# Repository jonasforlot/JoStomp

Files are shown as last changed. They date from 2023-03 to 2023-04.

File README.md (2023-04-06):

# JoStomp HX

This project is a mini MIDI controller for HX Stomp. It allows easy access to the 3 snapshots of a preset, while retaining the possibility of remaining in Footswitch mode on the HX. This offers many more possibilities and flexibility than a double TRS footswitch.
This pedal is also configured to scroll through the presets and provides access to a mini RC20 type looper.

It's not my work ! I just followed mattzws' advice on this page (the article is incredibly clear and detailed !) :

https://github.com/mattzzw/midi_muppet_hx_2btn

A big thanks to him !

I just customized this pedal by adding a button, then modified the code to suit my needs ;)

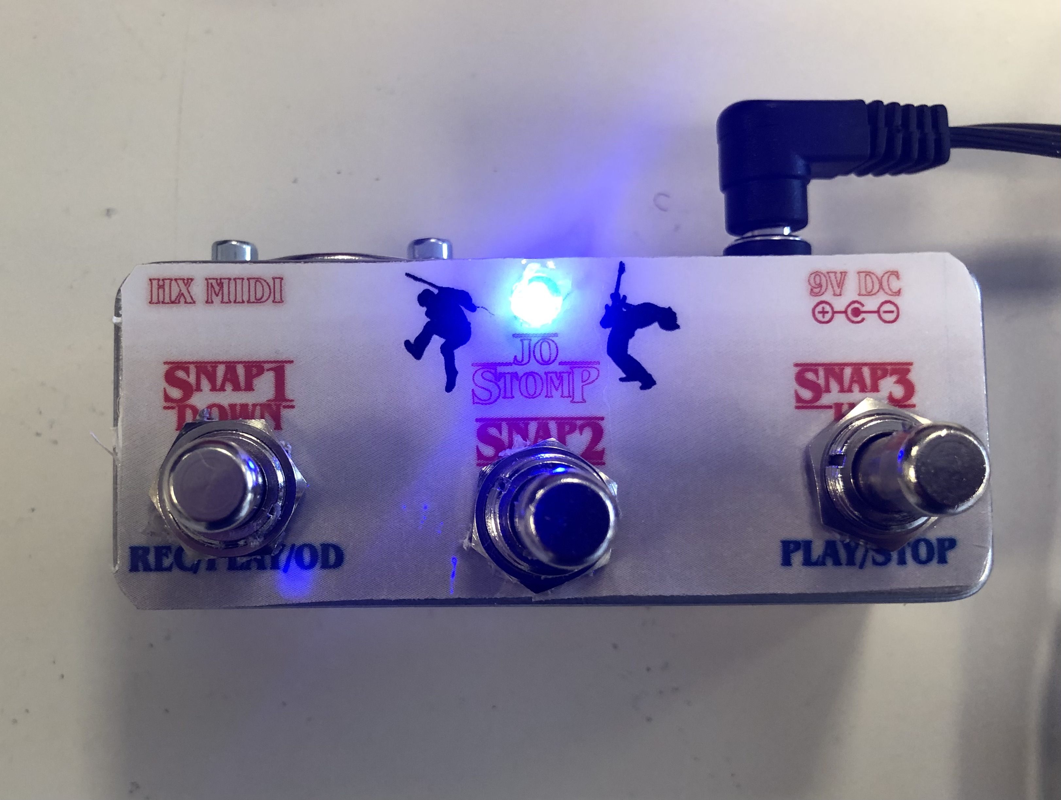
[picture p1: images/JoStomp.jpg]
JoStomp HX


**DEMO VIDEO HERE**
me (https://www.youtube.com/watch?v=dttxhMk9ur8&t=41s)

<a href="https://www.youtube.com/watch?v=dttxhMk9ur8&t=41s" target="_blank">DEMO VIDEO</a>

The JoStomp HX can

- select the three **snapshots**
- **scroll** up/down through **presets** 
- act as a two button **LOOPER** controller
    
    ... and can do more if we want !
    
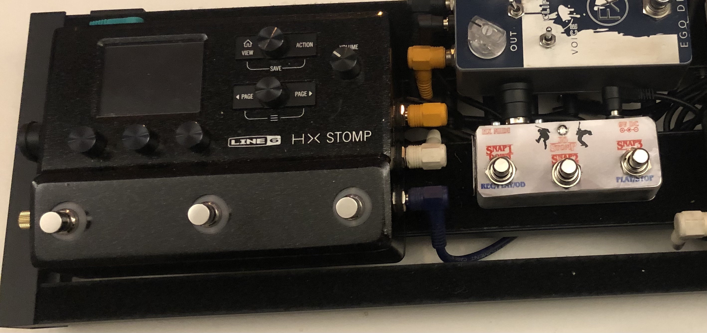
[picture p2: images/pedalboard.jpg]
pedalboard


## JoStomp Modes

| Mode |  LED  |
|---|---|
| Snapshot| **Green** |
| Scroll preset|  **Red** |
| Looper  | **Purple** ----------> **FEATURES** ->  Record : **flash red**  -----  Play : **green**  -----  Overdub : **yellow**|

To select a mode (snapshot or scroll presets), press and hold  button **2**

## Using the Modes:
| Mode |  Actions  |
|---|---|
| SCROLL Mode |  <ul><li>buttons **1/3** : preset down/up</li><li>button **2** **long** : mode SNAPSHOT</li><li>buttons **1+3** **both long**: LOOPER mode</li></ul> | 
| SNAPSHOT Mode | <ul><li>buttons **1/2/3** : select snapshot</li><li> button **2** **long** : mode SCROLL</li><li>buttons **1+3** **both long**: LOOPER mode</li></ul> | 
| LOOPER Mode | <ul><li>button **1** : record/play/overdub</li><li>button **3** : play/stop /undo (**long**)</li><li>button **2** : select mode HX (presets, snapshots, footswitch)</li><li>buttons **1+3** **both long**: mode SNAPSHOT</li><li>button **2** **long** : mode SNAPSHOT</li></ul> | 

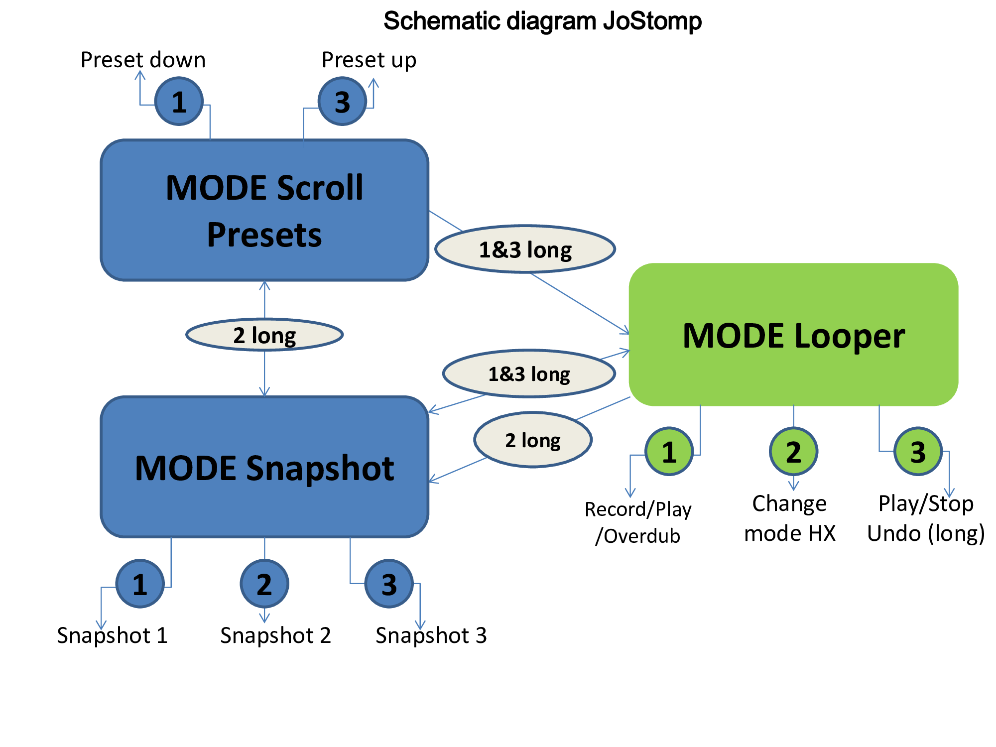
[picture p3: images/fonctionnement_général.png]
fonctionnement


## Setting the MIDI Channel
MIDI channel can be set to any value between 1 and 16. HX Stomp listens on channel 1 per default.

To change the MIDI Channel:
- Press and hold button **1** while powering up the JoStomp. After a second the device will indicate the currently set MIDI channel by slowly flashing the green LED (1 flash = channel 1, ..., 16 flashes = channel 16).
- Press up to increase the MIDI channel or press dn to decrease the channel.
- Press and hold up and dn to exit MIDI channel configuration.

MIDI Channel configuration will be stored in EEPROM and will be loaded on restart.

## List of components

Global budget : 20 € !

- Stomp case: e.g. Hammond 1590A
- 3 momentary foot switches
- Arduino Pro Mini with programming headers populated (5V)
- MIDI/DIN Socket
- 2,1 mm power Socket
- LED RGB
- 5 x 220R resistors (5V version of Arduino)
- FTDI serial adaptor (for programming)
- Diode IN4147

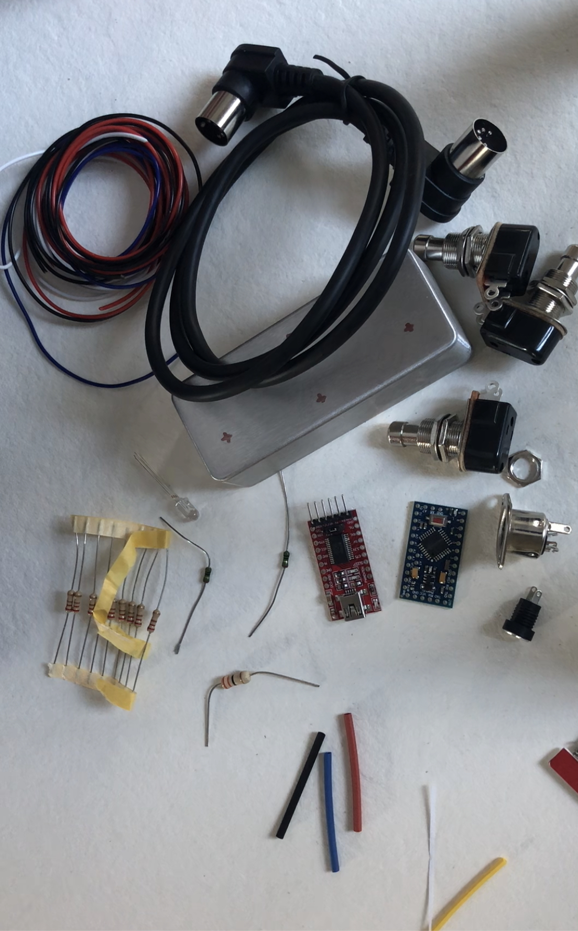
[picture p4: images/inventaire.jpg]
inventaire


## Drilling

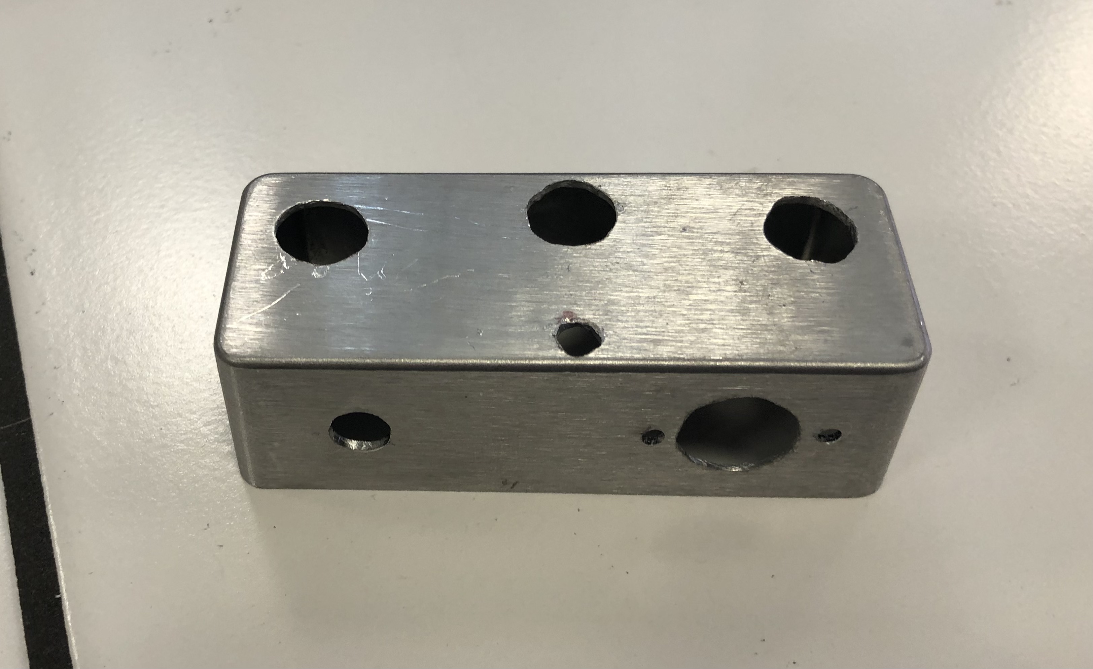
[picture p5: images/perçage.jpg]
perçage


## Wiring

| Component |  Pin  |
|---|---|
| Button 1/2/3| **D6, D7,D8** |
| LED RGB|  green red blue **D3, D4, D5** via **220R** resistor common cathond to ground |
| MIDI **pin 5** (data line) | **Arduino TX** pin via **220R** resistor|
| MIDI **pin 4** (voltage reference line) | **Arduino 5V/VCC** pin via **220R** resistor|
| **9V** from Power socket (ext)| **Arduino RAW** pin via diode (protection)|
| **GND** from Power socket center| **Arduino GNC** pin |

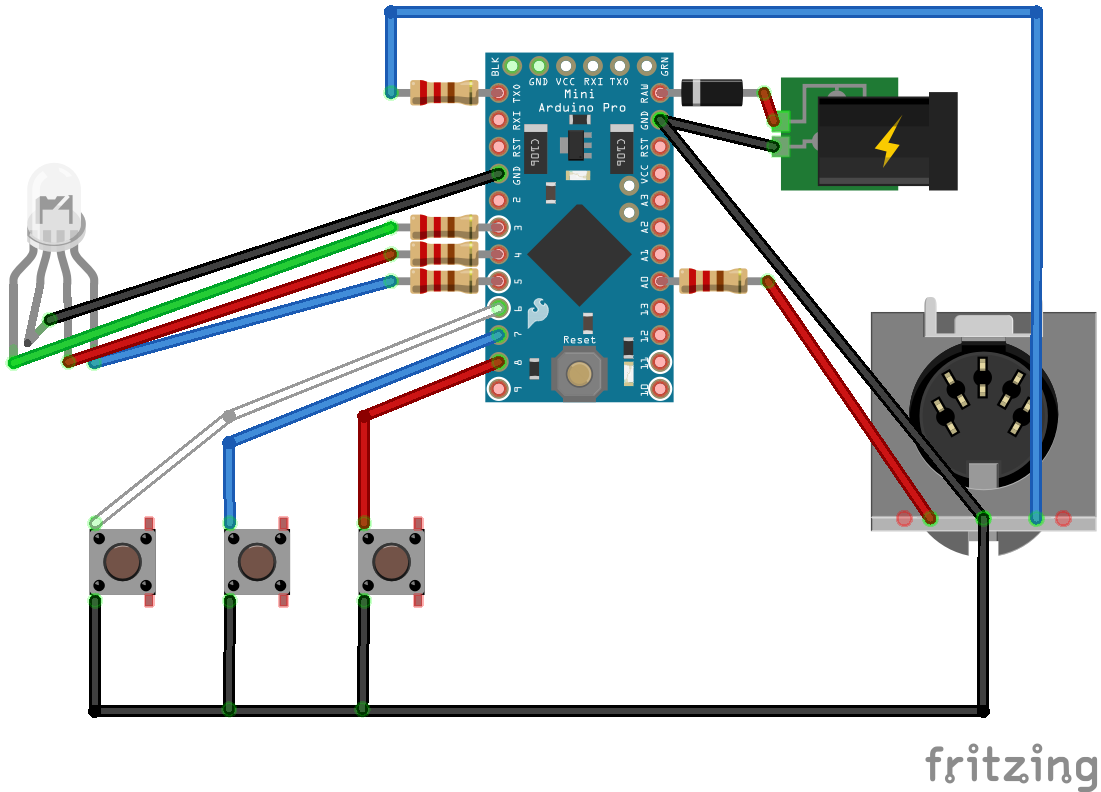
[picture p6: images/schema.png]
schema


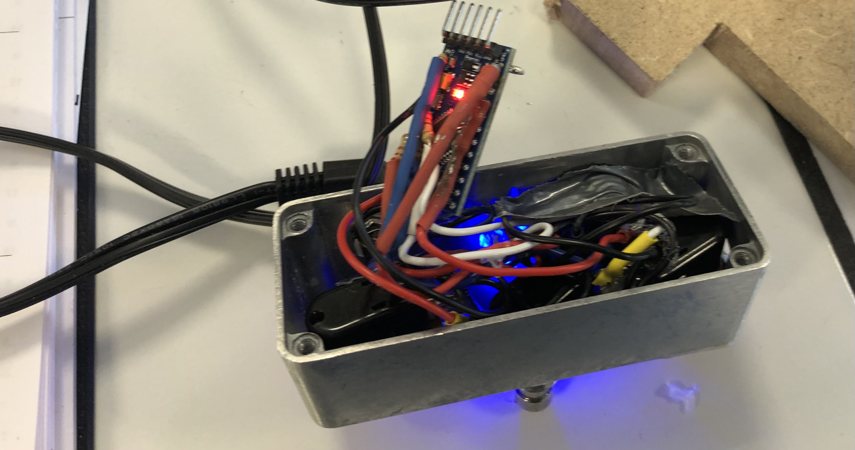
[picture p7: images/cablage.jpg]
cablage


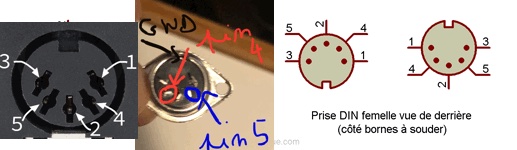
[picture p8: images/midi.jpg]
midi


## A nice little design ;)

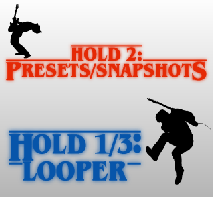
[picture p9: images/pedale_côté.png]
coté


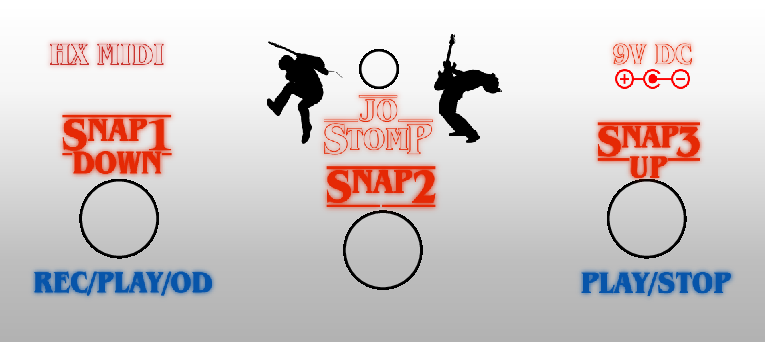
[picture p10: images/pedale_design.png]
design


## Code Arduino

The code requires the OneButton and the JC_Button library to be installed. You can find them in the Arduino library manager.

## Uploading the code 

Disconnect external power supply first! The FTDI adaptor will provide power.

Hook up the FTDI adaptor to the Arduino board, select "Arduino Pro or Pro Mini" in your Arduino IDE, load the code, compile, upload ... and enjoy !

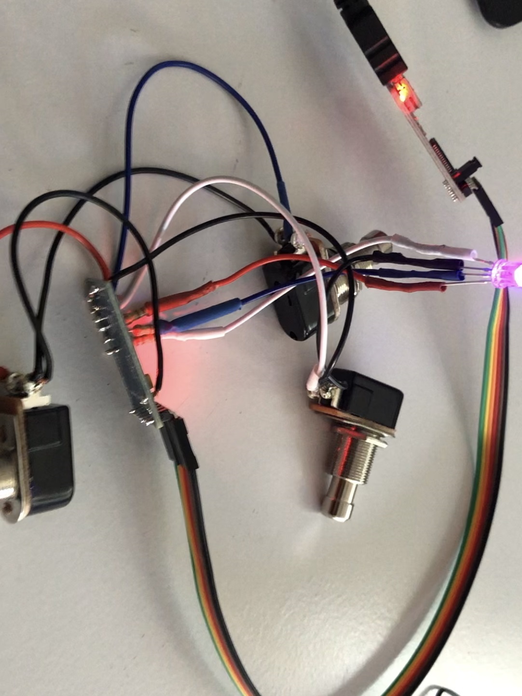
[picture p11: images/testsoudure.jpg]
testsoudures


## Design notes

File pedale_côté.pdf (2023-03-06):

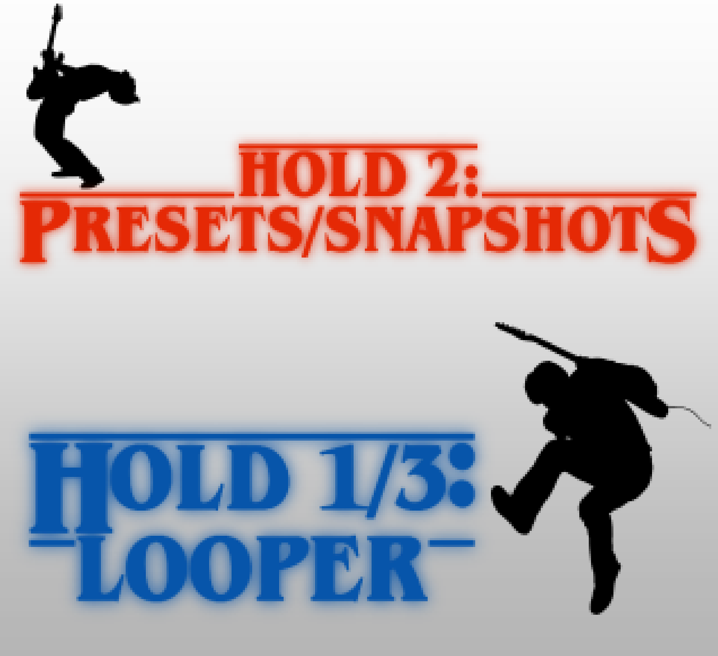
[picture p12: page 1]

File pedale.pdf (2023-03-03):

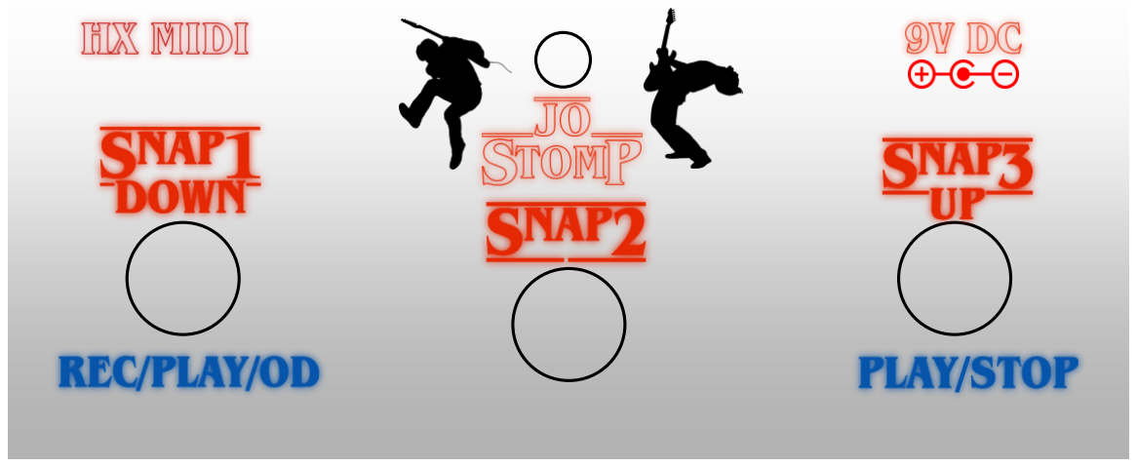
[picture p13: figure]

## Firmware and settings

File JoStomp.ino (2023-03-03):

/**************************************************************************

  BSD 3-Clause License

  Copyright (c) 2020, Matthias Wientapper
  All rights reserved.
  Customized by Jonas FORLOT
 

  Midi Foot Switch for HX Stomp
  =============================
  - Button 1/2/3 on pins D6, D7,D8
  - LED RGB green red blue       D3, D4, D5
  - requires OneButton lib https://github.com/mathertel/OneButton
  - requires JC_Button lib https://github.com/JChristensen/JC_Button

  We are using two different button libraries for different purposes:
    - OneButton to detect a long press without detecting a short press first.
      This means the action will be evaluated on releasing the button,
      which is ok for most cases but bad for timing critical actions
      like when we are in looper mode.
    - JC_Button to detect a short press as soon as the button is pressed down.
      This button library is used in looper mode only.

  SCROLL Mode:   1/3 switches prog patches down/up
                 2 long : mode SNAPSHOT
                 1+3 long: LOOPER mode
                 
 
  SNAPSHOT Mode: 1/2/3 select snapshot 1/2/3
                 2 long : mode SCROLL
                 1+3 long: LOOPER mode
   
  LOOPER Mode:   1  record/play/overdub
                 3  play/stop undo(long)
                 2  select mode HX (presets, snapshots, footswitch)
                 3 long  toggles undo/redo
                 2 long : mode SNAPSHOT

**************************************************************************/

#include <Wire.h>
#include <OneButton.h>
#include <JC_Button.h>

#include <EEPROM.h>

// GPIO pins used
#define BTN_UP 8
#define BTN_DN 6
#define BTN_MID 7
#define LED_GRN 3
#define LED_RED 4
#define LED_BLU 5

// EEPROM addresses
#define OP_MODE_ADDR      0  // stores looper mode of operation
#define MIDI_CHANNEL_ADDR 1  // stores the midi channel 

// Adjust red LED brightness 0-255 (full on was way too bright for me)
#define LED_RED_BRIGHTNESS 130
#define LED_GRN_BRIGHTNESS 100
#define LED_BLU_BRIGHTNESS 150
// on/off delay when we flash a LED
#define LED_FLASH_DELAY    30  



OneButton btnUp(BTN_UP, true);
OneButton btnDn(BTN_DN, true);
OneButton btnMid(BTN_MID, true);

Button jc_btnUp(BTN_UP);
Button jc_btnDn(BTN_DN);
Button jc_btnMid(BTN_MID);

enum modes_t {SCROLL, SNAPSHOT, LOOPER, CHANNEL_CFG, LOOPER_CFG};       // modes of operation
static modes_t MODE;       // current mode
static modes_t LAST_MODE;  // last mode
static modes_t MODE_BEFORE_SNAPSHOT; // last mode before snap shot mode

enum lmodes_t {PLAY, RECORD, OVERDUB, STOP, NONE};   // Looper modes
static lmodes_t LPR_MODE;

uint8_t midi_channel = 0;
void (*Reset)(void) = 0;

void setup() {
  
 

  // LEDs
  pinMode(LED_RED, OUTPUT);
  pinMode(LED_GRN, OUTPUT);
  pinMode(LED_BLU, OUTPUT);

  // Buttons:
  btnUp.setClickTicks(50);
  btnUp.attachClick(upClick);
  btnUp.attachLongPressStart(upLongPressStart);

  btnDn.setClickTicks(50);
  btnDn.attachClick(dnClick);
  btnDn.attachLongPressStart(dnLongPressStart);

  btnMid.setClickTicks(50);
  btnMid.attachClick(midClick);
  btnMid.attachLongPressStart(midLongPressStart);


  // Set MIDI baud rate:
  Serial.begin(31250);



  // restore MODE from EEPROM
  MODE = (modes_t) EEPROM.read(OP_MODE_ADDR);
  if (MODE > 4){
    // no valid value in eeprom found. (Maybe this is the first power up ever?)
    MODE = SNAPSHOT;
  }
    


 // restore MIDI channel
  midi_channel = EEPROM.read(MIDI_CHANNEL_ADDR);
  if (midi_channel > 15){ 
    // set channel to 0 if data not valid
    EEPROM.update(MIDI_CHANNEL_ADDR, 0);
    midi_channel = 0;
  } 

 if (digitalRead(BTN_DN) == 0 && digitalRead(BTN_UP) == 1) {
    // btn dn pressed: configure MIDI channel
      MODE = CHANNEL_CFG;
   
    flashLED(20, LED_GRN, LED_FLASH_DELAY);
    // 'display' configure MIDI channel
    delay(1000);
    
    flashLED(midi_channel + 1, LED_GRN, 500);
  }

 

  // restore mode on HX Stomp as well
  if (MODE == SNAPSHOT){
    midiCtrlChange(71, 0); // set stomp mode
  }
  else if (MODE == LOOPER){ 
    midiCtrlChange(71, 0); // set stomp mode
  }
  else if (MODE == SCROLL) {   
    midiCtrlChange(71, 0); // set stomp mode
  }

 

  // indicate mode via LEDs
  if (MODE == LOOPER) {
//    flashRedGreen(10);
    digitalWrite(LED_GRN, LOW);
    digitalWrite(LED_RED, LOW);
    digitalWrite(LED_BLU, LOW);
    flashLED(5, LED_GRN, LED_FLASH_DELAY);
     
   

    
    // we are in looper mode, so we are using the jc_button class for action on button press
    // (OneButton acts on button release)
    jc_btnUp.begin();
    jc_btnDn.begin();
    
    
  }
  else if (MODE == SCROLL){
    digitalWrite(LED_GRN, LOW);
    digitalWrite(LED_RED, LOW);
    digitalWrite(LED_BLU, LOW);
    flashLED(5, LED_RED, LED_FLASH_DELAY);
  }
    
  else if (MODE == SNAPSHOT){
    digitalWrite(LED_GRN, LOW);
    digitalWrite(LED_RED, LOW);
    digitalWrite(LED_BLU, LOW);
    flashLED(5, LED_BLU, LED_FLASH_DELAY);
  }
    

  // Looper default state
    LPR_MODE = NONE;

}


void loop() {

//  affichage();
  if (MODE == LOOPER) {
    
    
  
    jc_btnDn.read();                   // DN Button handled by JC_Button
    btnUp.tick();                   // Up Button handled by OneButton
    btnMid.tick();
    if (jc_btnDn.wasPressed() && digitalRead(BTN_UP) == 1)          // attach handler
      jc_dnClick();
      

  } else {
    btnUp.tick();                   // both buttons handled by OneButton
    btnDn.tick();
    btnMid.tick();
    
  }

  handle_leds();
// 
}

/* ------------------------------------------------- */
/* ---       OneButton Callback Routines          ---*/
/* ------------------------------------------------- */

void dnClick() {
  switch (MODE)
  {
    case SCROLL:
      patchDown();
      flashLED(2, LED_RED, LED_FLASH_DELAY);
      break;
    case SNAPSHOT:
      midiCtrlChange(69, 0); // snapshot 1
      flashLED(2, LED_RED, LED_FLASH_DELAY);
      break;
    case LOOPER:
      switch (LPR_MODE) {
        case NONE:
          LPR_MODE = RECORD;
          midiCtrlChange(60, 127);  // Looper record
          break;
        case STOP:
          LPR_MODE = RECORD;
          midiCtrlChange(60, 127);  // Looper record
          break;
        case RECORD:
          LPR_MODE = PLAY;
          midiCtrlChange(61, 127); // Looper play
          break;
        case PLAY:
          LPR_MODE = OVERDUB;
          midiCtrlChange(60, 0);    // Looper overdub
          break;
        case OVERDUB:
          LPR_MODE = PLAY;
          midiCtrlChange(61, 127); // Looper play
          break;
      }
      break;
    case CHANNEL_CFG:
      if(midi_channel > 0)
        midi_channel--;     
     
      flashLED(midi_channel+1, LED_GRN, 500);
      EEPROM.update(MIDI_CHANNEL_ADDR, midi_channel);    
    break;
       
  }
}
void upClick() {
  switch (MODE)
  {
    case SCROLL:
      patchUp();
      flashLED(2, LED_RED, LED_FLASH_DELAY);
      break;
    case SNAPSHOT:
      midiCtrlChange(69, 2); // Snapshot 3
      flashLED(2, LED_RED, LED_FLASH_DELAY);
      
   
      break;
    case LOOPER:
      switch (LPR_MODE) {
        case NONE:
        case STOP:
          LPR_MODE = PLAY;
          midiCtrlChange(61, 127); // Looper play
          break;
        case PLAY:
        case RECORD:
        case OVERDUB:
          LPR_MODE = STOP;
          midiCtrlChange(61, 0); // Looper stop
          break;
      }
      break;
    case CHANNEL_CFG:
      if(midi_channel < 15){
        midi_channel++;
      }
      else{
        midi_channel = 0;
      }      
     
      flashLED(midi_channel + 1, LED_GRN, 500);
      EEPROM.update(MIDI_CHANNEL_ADDR, midi_channel);
    break;
    

  }
}

void midClick() {
  switch (MODE)
  {
    case SCROLL:
      break;
    case SNAPSHOT:
      midiCtrlChange(69, 1); // Snapshot 2
      flashLED(2, LED_RED, LED_FLASH_DELAY);
      
     
      break;
    case LOOPER:
      midiCtrlChange(71, 4); // MODE Suivant
      flashLED(2, LED_RED, LED_FLASH_DELAY);
      
   
      break;
  }
  
}

void dnLongPressStart() {
  if (digitalRead(BTN_UP) == 1) {
    switch (MODE)
    {
      case SCROLL:
      while (digitalRead(BTN_DN) == 0){
        patchUp();
        flashLED(2, LED_RED, LED_FLASH_DELAY);
        delay(100);
      }
        
      case SNAPSHOT:
        break;
      case LOOPER:
        break;
    }
  }
}


void midLongPressStart() {
    switch (MODE) {
      case SCROLL:
        MODE = SNAPSHOT;
        digitalWrite(LED_GRN, LOW);
        digitalWrite(LED_RED, LOW);
        digitalWrite(LED_BLU, LOW);
        flashLED(5, LED_RED, LED_FLASH_DELAY);
        break;
      case SNAPSHOT:
        MODE = SCROLL;
        digitalWrite(LED_GRN, LOW);
        digitalWrite(LED_RED, LOW);
        digitalWrite(LED_BLU, LOW);
        flashLED(5, LED_RED, LED_FLASH_DELAY);
        break;
      case LOOPER:
        // make sure to switch off looper
        midiCtrlChange(61, 0); // Looper stop
        midiCtrlChange(71, 0); // set stomp mode
        MODE = SNAPSHOT;
        digitalWrite(LED_GRN, LOW);
        digitalWrite(LED_RED, LOW);
        digitalWrite(LED_BLU, LOW);
        flashLED(5, LED_RED, LED_FLASH_DELAY);
        break;
      case CHANNEL_CFG:
        MODE = SNAPSHOT;
        break;
    }
    EEPROM.update(OP_MODE_ADDR, SNAPSHOT);
//    // reset the device to reboot in new mode
//    Reset();
  }


  
void upLongPressStart() {
  if (digitalRead(BTN_DN) == 0) {
    // yay, both buttons pressed!
    // Toggle through modes
    switch (MODE) {
      case SCROLL:
        MODE = LOOPER;
        break;
      case LOOPER:
        midiCtrlChange(61, 0); // Looper stop
        MODE = SNAPSHOT;
        break;
      case SNAPSHOT:
        MODE = LOOPER;
        break;
      case CHANNEL_CFG:
        MODE = LAST_MODE;
      break;
    }
    EEPROM.update(OP_MODE_ADDR, MODE);
    // reset the device to reboot in new mode
    Reset();
  }
  else{
    // regular long press event:
    switch (MODE)
    {
      case SCROLL:
      while (digitalRead(BTN_UP) == 0){
        flashLED(2, LED_RED, LED_FLASH_DELAY);
        patchUp();
        delay(100);
      }
        break;
      case SNAPSHOT:
        break;
      case LOOPER:  
        switch (LPR_MODE) {
          case NONE:
          case PLAY:
          case STOP:         
            midiCtrlChange(63, 127); // looper undo/redo
            flashLED(3, LED_RED, LED_FLASH_DELAY);
            break;
          case RECORD:
          case OVERDUB:
            break;
        }

        break;
    }
  }
}

/* ------------------------------------------------- */
/* ---       JC_Button Callback Routines          ---*/
/* ------------------------------------------------- */

void jc_dnClick() {
  switch (LPR_MODE) {
    case NONE:
      LPR_MODE = RECORD;
      midiCtrlChange(60, 127);  // Looper record
      break;
    case STOP:
      LPR_MODE = RECORD;
      midiCtrlChange(60, 127);  // Looper record
      break;
    case RECORD:
      LPR_MODE = PLAY;
      midiCtrlChange(61, 127); // Looper play
      break;
    case PLAY:
      LPR_MODE = OVERDUB;
      midiCtrlChange(60, 0);    // Looper overdub
      break;
    case OVERDUB:
      LPR_MODE = PLAY;
      midiCtrlChange(61, 127); // Looper play
      break;
  }
}



/* ------------------------------------------------- */
/* ---      Midi Routines                         ---*/
/* ------------------------------------------------- */

// Use these routines if you are using firmware 3.01 or older:

// HX stomp does not have a native patch up/dn midi command
// so we are switching to scroll mode and emulating a FS1/2
// button press.
/*
void patchUp() {
  midiCtrlChange(71, 1); // HX scroll mode
  delay(30);
  midiCtrlChange(50, 127); // FS 2 (up)
  midiCtrlChange(71, 0);  // HX stomp mode
}

void patchDown() {
  midiCtrlChange(71, 1);   // HX scroll mode
  delay(30);
  midiCtrlChange(49, 127); // FS 1 (down)
  midiCtrlChange(71, 0);   // HX stomp mode
}
*/

// Added in Firmware 3.10:
//New MIDI message: CC 72 value 64-127 = next preset, value 0-63 = previous preset
void patchUp() {
  
  midiCtrlChange(72, 127); // next preset
  delay(200);

}

void patchDown() {
 
  midiCtrlChange(72, 0);   // prev preset
  delay(200);

}


void midiProgChange(uint8_t p) {
  Serial.write(0xc0 | midi_channel); // PC message
  Serial.write(p); // prog
}
void midiCtrlChange(uint8_t c, uint8_t v) {
  Serial.write(0xb0 | midi_channel); // CC message
  Serial.write(c); // controller
  Serial.write(v); // value

}

/* ------------------------------------------------- */
/* ---      Misc Stuff                            ---*/
/* ------------------------------------------------- */
void flashLED(uint8_t i, uint8_t led, uint8_t del)
{
  uint8_t last_state;
  last_state = digitalRead(led);

  for (uint8_t j = 0; j < i; j++) {
    digitalWrite(led, HIGH);
    delay(del);
    digitalWrite(led, LOW);
    delay(del);
  }
  digitalWrite(led, last_state);
}

void flashRedGreen(uint8_t i) {
  uint8_t last_state_r;
  uint8_t last_state_g;
  last_state_r = digitalRead(LED_RED);
  last_state_g = digitalRead(LED_GRN);


  for (uint8_t j = 0; j < i; j++) {
    digitalWrite(LED_RED, LOW);
    analogWrite(LED_GRN, LED_GRN_BRIGHTNESS);
    delay(75);
    analogWrite(LED_RED, LED_RED_BRIGHTNESS);
    digitalWrite(LED_GRN, LOW);
    delay(75);
  }
  digitalWrite(LED_RED, last_state_r);
  digitalWrite(LED_GRN, last_state_g);
}

void handle_leds() {
  static unsigned long next = millis();

  switch (MODE) {
    case SCROLL:
      // solid red
      digitalWrite(LED_GRN, LOW);
      digitalWrite(LED_BLU, LOW);
      analogWrite(LED_RED, LED_RED_BRIGHTNESS);
      //digitalWrite(LED_RED, HIGH);
      break;
    case SNAPSHOT:
      // solid blue
      analogWrite(LED_BLU, LED_BLU_BRIGHTNESS);
      digitalWrite(LED_GRN, LOW);
      digitalWrite(LED_RED, LOW);
      break;
    case LOOPER:
      switch (LPR_MODE) {
        case NONE:
          // violet
          analogWrite(LED_RED, LED_RED_BRIGHTNESS);
          analogWrite(LED_BLU, LED_BLU_BRIGHTNESS);
          digitalWrite(LED_GRN, LOW);
        case STOP:
          digitalWrite(LED_GRN, LOW);
          digitalWrite(LED_RED, LOW);
          digitalWrite(LED_BLU, LOW);
          break;
        case PLAY:
          analogWrite(LED_GRN, LED_GRN_BRIGHTNESS);
          digitalWrite(LED_BLU, LOW);
          digitalWrite(LED_RED, LOW);
          break;
        case RECORD:
          
           // blink red
          if (millis() - next > 500) {
            next += 500;
            digitalWrite(LED_RED, !digitalRead(LED_RED));
          }
          break;
        case OVERDUB:
          // yellow
          digitalWrite(LED_BLU, LOW);
          analogWrite(LED_GRN, LED_GRN_BRIGHTNESS);
          analogWrite(LED_RED, LED_RED_BRIGHTNESS);
          break;
      }
      
      break;
  }
}
